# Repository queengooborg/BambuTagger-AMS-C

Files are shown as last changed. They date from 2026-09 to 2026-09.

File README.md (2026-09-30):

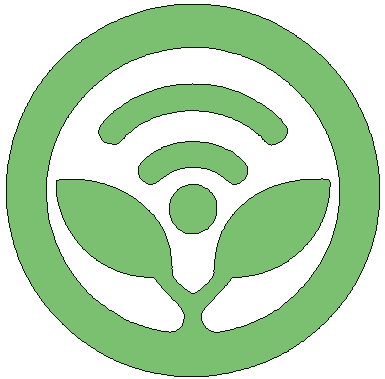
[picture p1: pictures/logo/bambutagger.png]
#  BambuTagger-AMS-C

Multi-spool NFC tag reader for Bambu Lab printers. Reads 4 Bambu Lab filament spool tags via RC522, displays live printer AMS tray data over MQTT, and sends RFID tag data to the printer/BMCU. Fully configurable via web interface with automatic AP fallback and OTA firmware updates.



<p align="center">
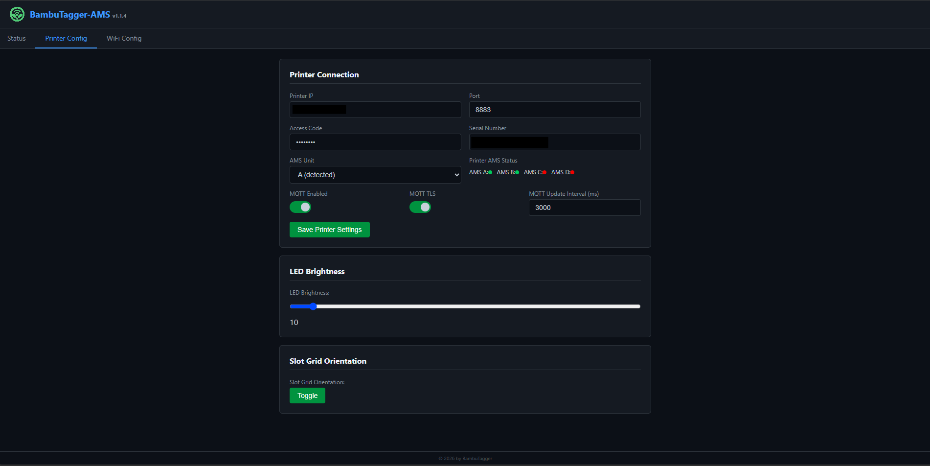
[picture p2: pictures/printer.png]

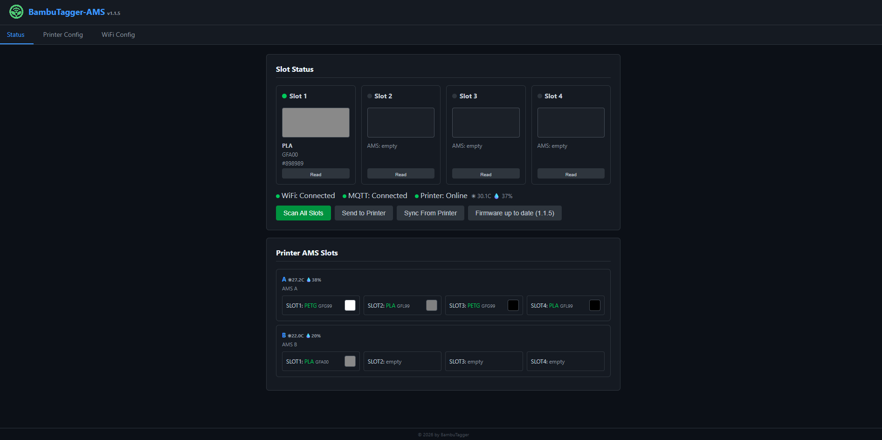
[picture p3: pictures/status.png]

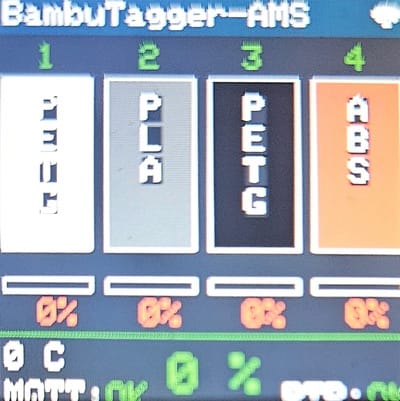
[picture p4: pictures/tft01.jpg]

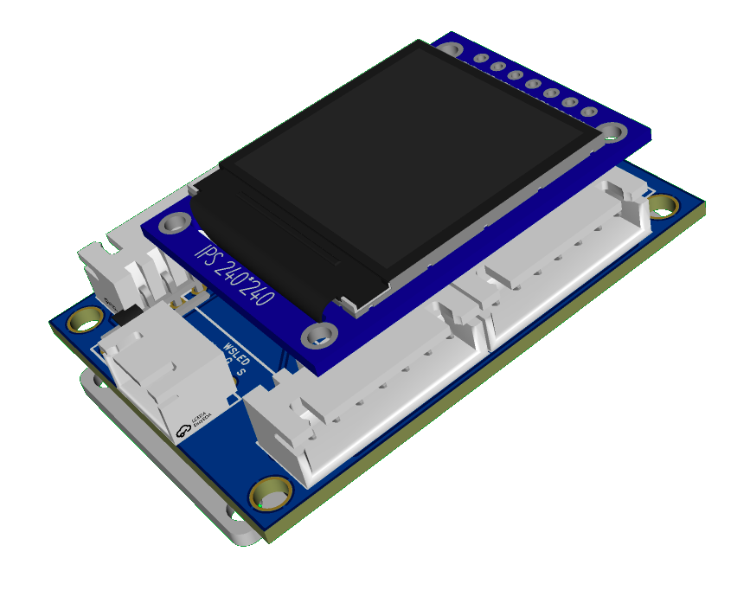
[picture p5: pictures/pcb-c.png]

</p>

Supported Tag Formats:

| Tag Type | Format |
| --- | --- |
| **Bambu Lab** | MIFARE Classic 1K |
| **SpoolEase** | NTAG, NDEF URI |
| **OpenSpool** | NTAG, NDEF JSON |
| **OpenTag3D** (v1 and v2) | NTAG, MIME binary |

---

## Features

| Category | Details |
| --- | --- |
| **RFID** | 4x RC522 on shared SPI bus; MIFARE Classic 1K (Bambu Lab) + NTAG (SpoolEase/OpenTag3D/OpenSpool) auto-detection |
| **Key derivation** | HKDF-SHA256 with Bambu Lab salt — no hardcoded keys |
| **Tag parsers** | OpenTag3D MIME binary, OpenSpool JSON, SpoolEase NDEF URI, nested NDEF recursion |
| **Live AMS sync**  | Reads tray data (material, color, type) from printer over MQTT |
| **BMCU support** | Sends `ams_filament_setting` with correct `tray_type`, `tray_color`, `nozzle_temp_min/max` |
| **TFT display** | 240×240 1.3" ST7789VW with boot splash, live AMS tray data, OTA progress, BME280 temp/humidity |
| **LEDs** | 4x WS2812 addressable LEDs with per-slot color from printer AMS tray data |
| **Web UI** | 3-tab SPA: Status (merged slots + color swatches), Printer Config, WiFi Config |
| **MQTT bridge** | Subscribes to printer status, publishes `ams_filament_setting` commands |
| **WiFi** | Auto-STA on boot; AP fallback `192.168.4.1` with captive portal |
| **OTA updates** | One-click firmware update from GitHub Releases with TFT progress bar |
| **CI/CD** | GitHub Actions: build on commit, release on version tags |

---

## Hardware

This build assumes you have a basic level of microprocessor and breadboard/soldering experience.

### Bill of Materials

There are two options for ESP32 boards: the ESP-WROOM-32 Dev board, or the ESP32-S3-DevKitC-1.

#### ESP-WROOM-32

This is the original board.

| Component | Required | Notes | Buy/Download/Get |
| --- | --- | --- | --- |
| **ESP32** Dev Module | **Yes**  | Base board | https://de.aliexpress.com/item/1005006589341221.html |
| Custom **PCB** | Optional | DIY PCB from JLPCB (use PCB v1.2 or newer) | https://oshwlab.com/bambutagger/project_hdkkdlsn |
| 3D-Printed **Case**  | Optional | | For [AMS](./3d-prints/ESP-WROOM-32/BambuTagger-AMS.3mf)<br /> For [AMS 2 Pro](./3d-prints/ESP-WROOM-32/BambuTagger-AMS2Pro.3mf) |

#### ESP32-S3-DevKitC-1

| Component | Required | Notes | Buy/Download/Get |
| --- | --- | --- | --- |
| **ESP32** Dev Module | **Yes**  | Base board | |
| Custom **PCB** | Optional | DIY PCB designed by @Digitalpunk | [Gerber Files](./PCB/ESP32-S3-DevKitC-1) |

#### Common Components

| Component | Required | Notes | Buy/Download/Get |
| --- | --- | --- | --- |
| **100µF Capacitor** | **Yes** | Regulates power for components | |
| **4x RC522** RFID/NFC Readers | **Yes** | SPI interface, shared bus | https://de.aliexpress.com/item/1005006233005745.html  |
| **240×240 1.3" TFT** | **Yes** | ST7789VW SPI Display | https://www.aliexpress.com/item/1005007094147766.html |
| **4x WS2812** Addressable LEDs | Optional | Daisy-chained, single data pin | https://de.aliexpress.com/item/32560280169.html |
| **BME280** 3.3V Sensor | Optional | Temperature/Humidity, I2C | https://de.aliexpress.com/item/1005006824236173.html  |
| **4x JST-XH 7-Pin** Connector+Cable | With Custom PCB | For PCB connections to RC522s  | |

### Wiring / Pin Assignments

If you are not using the custom PCB, you can manually wire all the components.

Connect the ESP32 to a 5V power input, either via the USB port or via the VCC/Vin pin.

The WS2812 LED must also be powered by 5V. If the ESP32 is powered via the USB port, the VCC/Vin pin becomes a 5V output, and can be used to power the LEDs. On some boards, you may need to short two pads (usually labeled VIN->VOUT) via soldering.

Connect the 100µF capacitor from the 3.3V to the ground. This capacitor helps regulate power and prevents back-powering the RC522 readers.

All other components will be powered by the 3.3V pin on the ESP32 board.

| Function | ESP-WROOM-32 | ESP32-S3-DevKitC-1 |
| --- | --- | --- |
| **RC522 SPI MOSI (Shared)** | 23 | 11 |
| **RC522 SPI MISO (Shared)** | 19 | 13 |
| **RC522 SPI SCK (Shared)**  | 18 | 12 |
| **RC522 #1 SS (SDA)** | 13 | 4 |
| **RC522 #1 RST** | 26 | 15 |
| **RC522 #2 SS (SDA)** | 12 | 5 |
| **RC522 #2 RST** | 25 | 16 |
| **RC522 #3 SS (SDA)** | 14 | 6 |
| **RC522 #3 RST** | 33 | 17 |
| **RC522 #4 SS (SDA)** | 27 | 7 |
| **RC522 #4 RST** | 32 | 18 |
| **TFT SDA (MOSI)** | 17 | 35 |
| **TFT SCL (SCK)** | 16 | 36 |
| **TFT DC** | 4 | 37 |
| **TFT RES** | 5 | 0 |
| **TFT BLK** | 2 | 45 |
| **WS2812 Data** | 15 | 14 |
| **BME280 SDA** | 21 | 48 |
| **BME280 SCL** | 22 | 47 |

---

## Firmware

### Flashing a Release

The easiest way to flash the board firmware is to use a web flashing utility like [ESPFlasher.app](https://espflasher.app/). Simply download the appropriate `firmware_merged.bin` from the [releases](https://github.com/queengooborg/BambuTagger-AMS-C/releases) page and upload it to the flashing utility.

- ESP-WROOM-32 / ESP32 Dev Module - `esp32dev-firmware_merged.bin`
- ESP32-S3-DevKitC-1 - `esp32-s3-devkitc-1-firmware_merged.bin`

Alternatively, if you have `esptool` set up locally, you may run the following command:

- ESP-WROOM-32 / ESP32 Dev Module - `esptool write-flash 0x0 esp32dev-firmware_merged.bin`
- ESP32-S3-DevKitC-1 - `esptool --chip esp32s3 write-flash 0x0 esp32-s3-devkitc-1-firmware_merged.bin`

### Building from Source

To build from source, you may either use Visual Studio Code or run commands in the terminal. The following sections will cover setup for running commands in the terminal.

#### Initial Setup

To setup the local development environment, you can either use Visual Studio Code, or run the `./setup.sh` command. The command will create a Python virtual environment, using the virtualenv manager if one is available, and install dependencies.

> [!NOTE]
> To reactivate the virtualenv at a later time (if you don't have a virtualenv manager), simply run:
>
> ```sh
> source .venv/bin/activate
> ```

#### Build and Upload

```sh
# ESP32-WROOM / ESP32 Dev Module
pio run -e esp32-ams-c
pio run -e esp32-ams-c -t upload

# ESP32-S3-DevKitC-1
pio run -e esp32-s3-devkitc-1
pio run -e esp32-s3-devkitc-1 -t upload
```

---

## How to Use

### Initial Setup

Once the firmware has been flashed for the first time, the ESP32 will initialize and create its own WiFi access point called "BambuTagger-AMS". Connect to the WiFi network to access the web-based configuration panel.

> [!NOTE]
> The configuration panel should automatically appear as a captive portal. If it does not, manually go to it by going to `http://192.168.4.1` in your browser.

Configure your WiFi network first by typing in the SSID name and password, then click "Save WiFi Settings". The ESP32 will reboot automatically. If the network configuration succeeded, you can now switch to your primary WiFi. If it did not, the WiFi access point will reinitialize, allowing you to reconnect.

Once WiFi configuration is completed, reconnect to your device by navigating to `[Device Name].local` (default: `BambuTagger-AMS.local`) or via the IP address displayed on the TFT screen.

Enter in your printer settings on the printer config page, including the IP, serial number and access code.

> [!IMPORTANT]
> Your printer MUST be in LAN Only Mode and Developer Mode. The printer will refuse all connections otherwise.

### Using with Printer

The project is designed with the intent of placing a reader at each AMS slot, similar to how the existing readers are placed. With each reader placed, tag scanning will happen automatically as filament is loaded normally.

--

## Technical Details

### WiFi & Connectivity

#### AP Mode

| Scenario | Behavior |
| --- | --- |
| No WiFi configured | Opens AP immediately |
| WiFi connection fails | Opens AP after 15 seconds |
| AP active, credentials exist | Retries STA connection every 30 seconds |
| STA connects while AP active | Closes AP, switches to normal mode |

**AP Details:**

- **SSID**: Device name (default: `BambuTagger-AMS`)
- **Security**: Open (no password)
- **IP**: `192.168.4.1`
- **Captive portal**: DNS redirects all domains to the config page

#### SSID Mode

When the ESP32 module is connected to an existing network, the IP address will display on the TFT screen. Alternatively, you may navigate to `[Device Name].local` (default: `BambuTagger-AMS.local`).

---

### Web Interface

Open a browser to the ESP32's IP (shown on TFT), `[Device Name].local`, or `http://192.168.4.1` (in AP mode).

| Tab | Description |
| --- | --- |
| **Status** | Merged slot status with AMS data + scanned tag data, color swatches, printer AMS cards, OTA button |
| **Printer Config** | Printer IP, Port (8883), Access Code, Serial Number, AMS Unit selector (A/B/C/D), MQTT settings |
| **WiFi Config** | SSID, Password, Device Name |

---

### TFT Display (240×240 1.3" ST7789VW)

The TFT display has two modes:

```
┌─────────────────────────────────┐
│ Device Name               WiFi  │  ← status bar (white bg)
├─────────────────────────────────┤
│    1       2                    │
│ ┌─────┐ ┌─────┐ ┌─────┐ ┌─────┐ │  ← color swatch + percentage
│ │  P  │ │     │ │     │ │     │ │
│ │  L  │ │     │ │     │ │     │ │
│ │  A  │ │     │ │     │ │     │ │
│ │     │ │     │ │     │ │     │ │
│ │     │ │     │ │     │ │     │ │
│ └─────┘ └─────┘ └─────┘ └─────┘ │
│                                 │
│  100%                           │
├─────────────────────────────────┤
│ 22C           45%               │  ← temperature, humidity
│ MQTT:OK                  PTR:OK │  ← status line
└─────────────────────────────────┘
```

```
┌─────────────────────────────────┐
│ Device Name               WiFi  │  ← status bar (white bg)
├─────────────────────────────────┤
│ 1: PLA     [■] #C0C0C0FF  100%  │  ← color swatch + percentage
│ 2: empty                        │
│ 3: empty                        │
│ 4: empty                        │
├─────────────────────────────────┤
│ 22C           45%               │  ← temperature, humidity
│ MQTT:OK                  PTR:OK │  ← status line
└─────────────────────────────────┘
```

OTA progress shown on TFT with header/footer preserved:  
"OTA Update" → "Downloading..." → "Flashing... 45%" → auto-reboot

---

### Printer Communication

#### Subscribe

- **Topic**: `device/<serial>/report`
- **Data**: `push_status` (periodic, ~3KB), `get_version` responses

#### Publish

- **Topic**: `device/<serial>/request`

**`ams_filament_setting`** structure:

```json
{
  "print": {
    "sequence_id": "0",
    "command": "ams_filament_setting",
    "ams_id": 0,
    "tray_id": 0,
    "tray_info_idx": "GFA00",
    "tray_color": "RRGGBBFF",
    "nozzle_temp_min": 190,
    "nozzle_temp_max": 230,
    "tray_type": "PLA"
  }
}
```

- `tray_type` derived from filament index prefix (GFA→PLA, GFG→PETG, etc.)
- `tray_color` forced to RRGGBBFF format
- `nozzle_temp_min/max` from tag block 6

---

### Tag Format & Reading

The following tag types are supported:

| Tag Type | Format | Example |
| --- | --- | --- |
| **Bambu Lab** | MIFARE Classic 1K | `Bambu - PLA · C12E1FFF · 1000g/1000g` |
| **SpoolEase** | NTAG, NDEF URI | `SpoolEase - PLA · 000000FF · 1000g/1036g` |
| **OpenSpool** | NTAG, NDEF JSON | `OpenSpool - ASA-AF · F078B4FF · 1000g/1000g` |
| **OpenTag3D** (v1 and v2) | NTAG, MIME binary | `OpenTag3D v2.003 - ASA-AF · F078B4FF · 1000g/1000g` |

#### Bambu Lab (MIFARE Classic 1K)

| Block | Content |
| ----- | --- |
| 0 | UID (4 bytes) |
| 1 | Variant ID + Material index (e.g. "GFA00") |
| 2 | Filament type short name |
| 4 | Detailed type string (e.g. "PLA Basic") |
| 5 | RGBA color (bytes 0-3) + spool weight LE (bytes 4-5) |
| 6 | Nozzle temps (bytes 8-11 LE) |

#### SpoolEase (NTAG, NDEF URI)

URL format: `https://tag.spoolease.io/S1/?TG=...&M=PLA&CC=000000FF&SC=GFL99&WL=1000&WE=179&WF=1215&NN=190&NX=240`

| Param | Field | Description |
| ----- | --- | --- |
| `M=`  | display type | e.g. "PLA", "PETG" |
| `SC=` | `materialType` | Bambu index for MQTT (e.g. "GFL99") |
| `CC=` | `colorHex` | RGBA hex (e.g. "000000FF") |
| `B=`  | `manufacturer` | Brand name (e.g. "Jayo") |
| `WL=` | `remainingGrams` | Remaining filament weight |
| `WE=` | empty spool | Empty spool weight |
| `WF=` | full spool | `totalGrams = WF - WE` |
| `NN=` | `nozzleTempMin`  | Min nozzle temp °C |
| `NX=` | `nozzleTempMax`  | Max nozzle temp °C |

#### OpenTag3D (NTAG, MIME binary)

The OpenTag3D spec can be read on [their website](https://opentag3d.info/spec).

### Authentication & Reading

- **Tag auto-detect**: SAK-based type detection (MIFARE 1K vs NTAG)
- **HKDF-SHA256** derives 16 per-sector Key A/B from 4-byte UID
- Bambu KDF salt/info vectors from reverse-engineered firmware
- Falls back to default key `0xFF...FF` for blank sectors
- Failed auth re-wakes tag via antenna power-cycle
- Dead readers auto-skipped (version register 0x92/0x91/0xB2 check)
- SPI: 1 MHz via `MFRC522_SPI`
- NTAG: page-level reads (page+=4, 4 pages per MIFARE_Read)

### Filament Type Mapping

| Prefix | Type |
| --- | ---- |
| GFA-GFE, GFL | PLA  |
| GFG | PETG |
| GFH, GFI | ABS  |
| GFJ | ASA  |
| GFK | TPU  |

---

### OTA Updates

- **Button**: "Update Firmware" on Status page (shows "Update to vX.Y.Z" or "up to date")
- **Overlay**: full-screen progress overlay with spinner, status text, progress bar
- **Endpoint**: `POST /api/ota` triggers update, `GET /api/ota-check` checks for newer version
- Downloads latest `.ino.bin` from GitHub Releases, flashes via `Update.h`
- 3 retry attempts with 5s stall detection, fresh HTTP client per attempt
- TFT shows "Checking version..." → "Downloading..." → "Flashing..." with percentage
- Device auto-reboots after successful flash, web UI auto-reloads

---

### Configuration Defaults

| Setting | Default |
| --- | --- |
| WiFi SSID | (empty) |
| WiFi Password | (empty) |
| Device Name | BambuTagger-AMS |
| Printer IP | 192.168.1.100 |
| Printer Port | 8883 |
| Access Code | (empty) |
| Printer Serial | (empty) |
| AMS Unit | A (0) |
| MQTT Enabled | Yes |
| MQTT TLS | No |
| MQTT Update Interval | 3000 ms |
| RFID Poll Interval | 100 ms |
| Firmware Version | 1.0.8 |

---

## Credits & References

- [RFID-Tag-Guide](https://github.com/Bambu-Research-Group/RFID-Tag-Guide)
- Display library: [Adafruit ST7735/ST7789](https://github.com/adafruit/Adafruit-ST7735-Library)
- RFID library: [MFRC522-spi-i2c-uart-async](https://github.com/miguelbalboa/rfid)
- OpenTag3D spec: [opentag3d.info](https://opentag3d.info)

---

## License

This project is licened under AGPLv3.
This project is provided as-is for personal and educational use.  
Bambu Lab trademarks and spool tag data formats are the property of Bambu Lab.

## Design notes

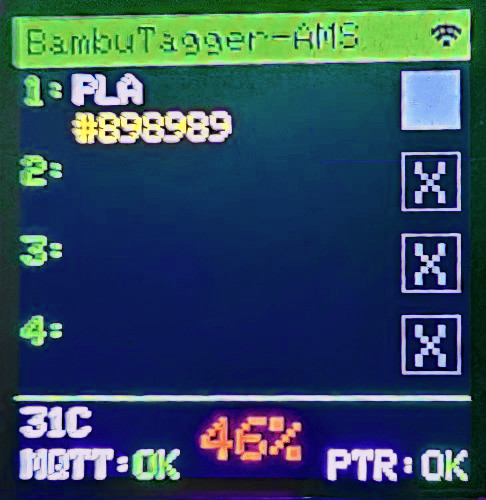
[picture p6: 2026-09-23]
pictures/tft02.jpg

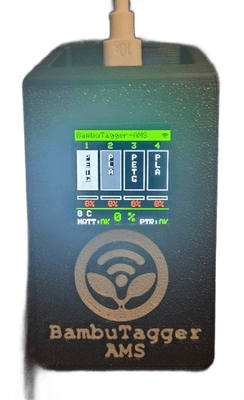
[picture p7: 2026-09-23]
pictures/BT-AMS-case.png

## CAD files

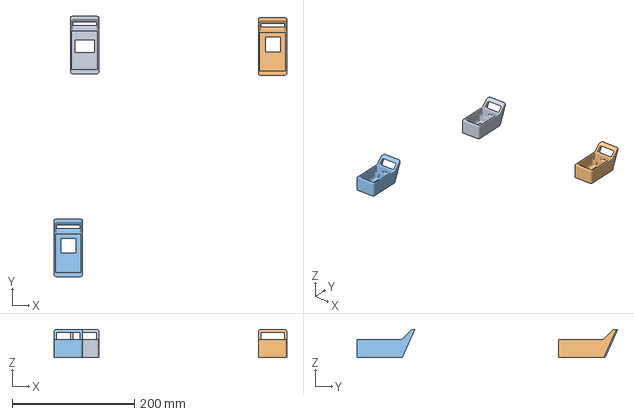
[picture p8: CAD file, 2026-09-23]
3d-prints/ESP-WROOM-32/BambuTagger-AMS.3mf
381.9 x 427.1 x 46.1 mm
BambuTagger-AMS
BambuTagger-AMS-C x 2

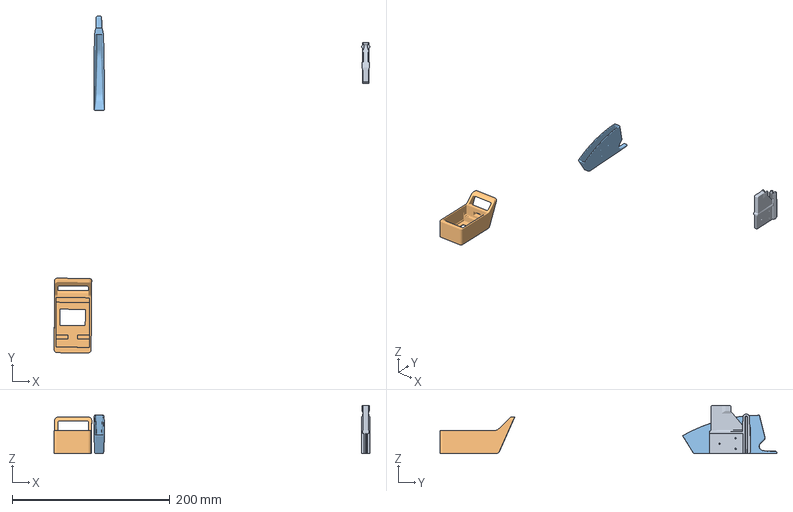
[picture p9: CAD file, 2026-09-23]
3d-prints/ESP-WROOM-32/BambuTagger-AMS2Pro.3mf
400.6 x 427.3 x 61.2 mm
BambuTagger-AMS (2).stl
BambuTagger-AMS.stl
BambuTagger-AMS (1).stl

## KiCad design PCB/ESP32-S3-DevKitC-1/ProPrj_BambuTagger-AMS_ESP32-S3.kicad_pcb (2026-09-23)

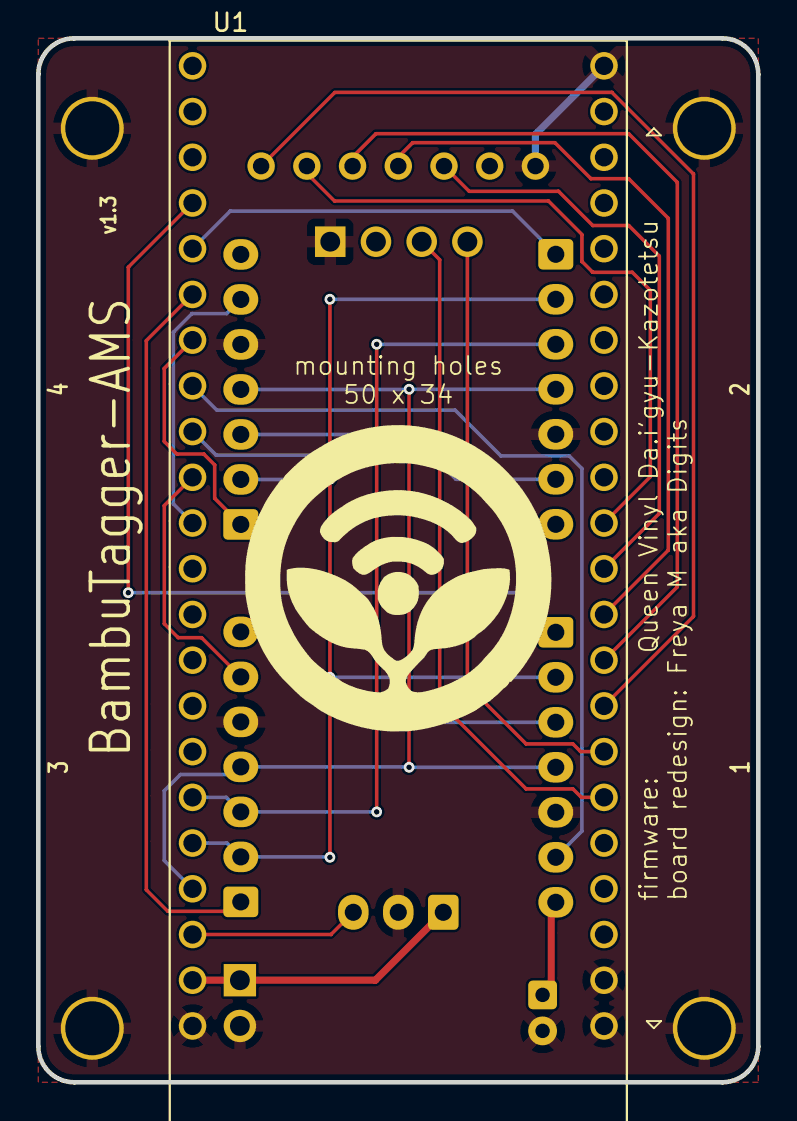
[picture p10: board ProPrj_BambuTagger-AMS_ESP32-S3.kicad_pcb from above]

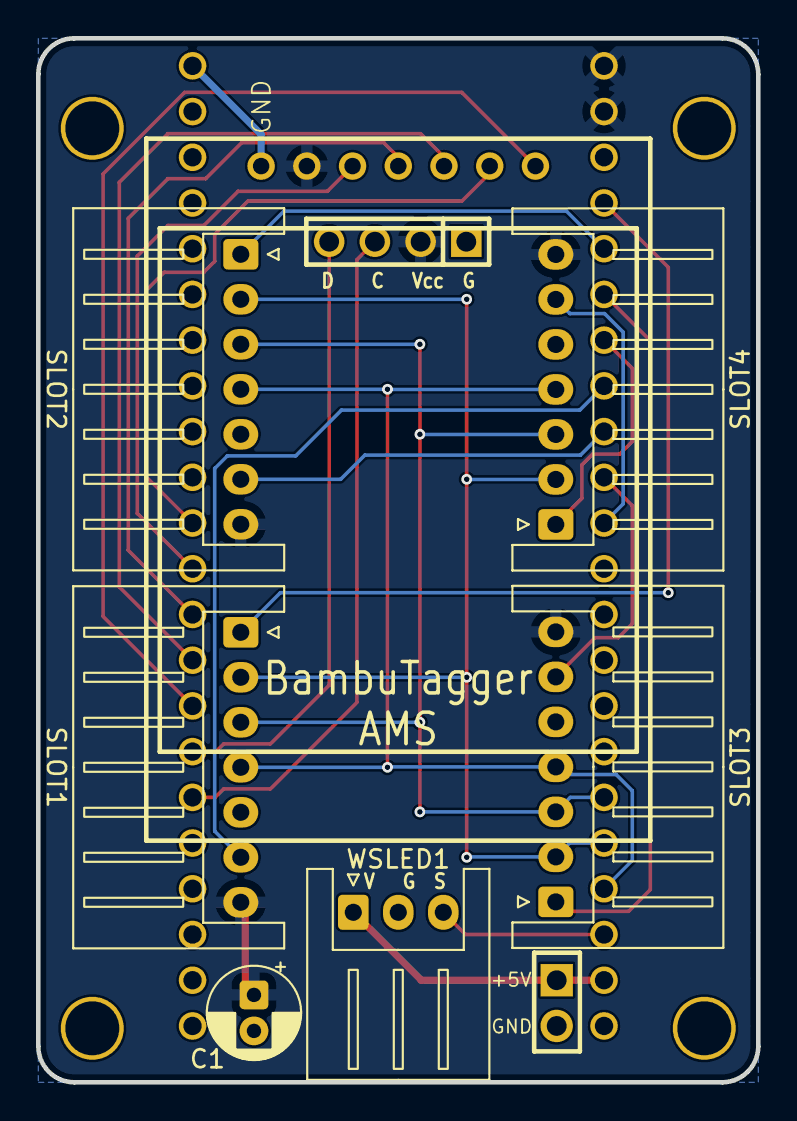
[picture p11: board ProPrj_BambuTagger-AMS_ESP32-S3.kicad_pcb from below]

Board: 2 copper layers, 40.0 x 58.0 mm, 10 parts (9 on the bottom side), 22 nets.

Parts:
5V: HDR-TH_2P-P2.54-H-M-W10.4
C1: 100uF; CP_Radial_D5.0mm_P2.00mm
SENSOR: HDR-TH_4P-P2.54-V-M
SLOT1, SLOT2, SLOT3, SLOT4: ZX-XH2.54-7PWZ; JST_XH_S7B-XH-A_1x07_P2.50mm_Horizontal
TFT: 240X240 1.3 TFT SPI DISPLAY
U1: ESP32-S3-DEVKITC-1U-N8R8; MODULE_ESP32-S3-DEVKITC-1U-N8R8
WSLED1: ZX-XH2.54-3PWZ; JST_XH_S3B-XH-A_1x03_P2.50mm_Horizontal

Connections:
3_3V: C1.1, SENSOR.2, SLOT1.7, SLOT2.7, SLOT3.7, SLOT4.7, TFT.6, U1.J1_1 (3V3), U1.J1_2 (3V3)
BLK: TFT.1, U1.J3_15 (GPIO45)
CS1: SLOT1.1, U1.J1_4 (GPIO4)
CS2: SLOT2.1, U1.J1_5 (GPIO5)
CS3: SLOT3.1, U1.J1_6 (GPIO6)
CS4: SLOT4.1, U1.J1_7 (GPIO7)
DC: TFT.2, U1.J3_11 (GPIO37)
GND: 5V.2, C1.2, SENSOR.1, SLOT1.5, SLOT2.5, SLOT3.5, SLOT4.5, TFT.7, U1.J1_22 (GND), U1.J3_1 (GND), U1.J3_21 (GND), U1.J3_22 (GND), WSLED1.2
MISO: SLOT1.4, SLOT2.4, SLOT3.4, SLOT4.4, U1.J1_19 (GPIO13)
MOSI: SLOT1.3, SLOT2.3, SLOT3.3, SLOT4.3, U1.J1_17 (GPIO11)
RES: TFT.3, U1.J3_14 (GPIO0)
RST1: SLOT1.6, U1.J1_8 (GPIO15)
RST2: SLOT2.6, U1.J1_9 (GPIO16)
RST3: SLOT3.6, U1.J1_10 (GPIO17)
RST4: SLOT4.6, U1.J1_11 (GPIO18)
SCK: SLOT1.2, SLOT2.2, SLOT3.2, SLOT4.2, U1.J1_18 (GPIO12)
SCL: SENSOR.3, U1.J3_17 (GPIO47)
SCLTFT: TFT.5, U1.J3_12 (GPIO36)
SDA: SENSOR.4, U1.J3_16 (GPIO48)
SDATFT: TFT.4, U1.J3_13 (GPIO35)
VCC: 5V.1, U1.J1_21 (5V0), WSLED1.1
WSLED: U1.J1_20 (GPIO14), WSLED1.3

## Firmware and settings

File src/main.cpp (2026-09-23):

/*
 * BambuTagger AMS - Multi-Spool NFC Tag Reader for Bambu Lab
 *
 * Arduino IDE: ESP32 Dev Module (Tools > Board > ESP32 > ESP32 Dev Module)
 *
 * Required libraries (install via Tools > Manage Libraries):
 *   - MFRC522-spi-i2c-uart-async
 *   - Adafruit NeoPixel by Adafruit    (v1.12.3+)
 *   - Adafruit GFX Library by Adafruit (v1.11.11+)
 *   - Adafruit ST7735 and ST7789 Library by Adafruit (v1.10.0+)
 *   - PubSubClient   by Nick O'Leary   (v2.8+)
 *   - ArduinoJson    by Benoit Blanchon (v6.21.5+)
 *
 * Wiring: see config.h for pin assignments
 */

#include <ESPmDNS.h>
#include <WiFi.h>
#include <DNSServer.h>
#include <HTTPClient.h>
#include <Update.h>
#include <Adafruit_BME280.h>
#include <HTTPUpdate.h>

#include <esp_http_client.h>
#include <esp_ota_ops.h>

#include "config.h"
#include "rfid_manager.h"
#include "led_manager.h"
#include "display_manager.h"
#include "web_server.h"
#include "bambu_printer.h"

SystemConfig cfg;
RfidManager rfidManager;
LedManager ledManager;
DisplayManager displayManager;
WebInterface webInterface;
BambuPrinter bambuPrinter;
DNSServer dnsServer;
Adafruit_BME280 bme;
float bmeTemp = 0;
float bmeHumidity = 0;
bool bmeOk = false;

bool wifiConnected = false;
bool apMode = false;
String localIP = "";
const byte DNS_PORT = 53;

void handleReboot();
void performOTAUpdate();
void connectWiFi();
void startCaptivePortal();
void updateLedStatus();

SET_LOOP_TASK_STACK_SIZE(16 * 1024);

void setup() {
  Serial.begin(115200);
  delay(1500);
  Serial.println();
  Serial.print(F("=== BambuTagger AMS v"));
  Serial.print(FIRMWARE_VERSION);
  Serial.println(F(" ==="));
  Serial.println(F("Multi-Spool NFC Tag Reader for Bambu Lab"));

  loadConfig(cfg);

  displayManager.begin(cfg.deviceName);
  Serial.println(F("TFT initialized"));
  displayManager.showBootScreen();
  displayManager.setLayout(cfg.layoutVertical);
  delay(2000);

  Wire.begin(I2C_SDA, I2C_SCL);
  bmeOk = bme.begin(0x76);
  if (!bmeOk)
    bmeOk = bme.begin(0x77);
  if (bmeOk) {
    Serial.println(F("BME280 sensor found"));
  } else {
    Serial.println(F("BME280 not found"));
  }

  Serial.print(F("Device: "));
  Serial.println(cfg.deviceName);

  ledManager.begin();
  Preferences prefs;
  prefs.begin("led", false);
  uint8_t savedBrightness = prefs.getUChar("brightness", LED_BRIGHTNESS);
  prefs.end();

  ledManager.setBrightness(savedBrightness);

  ledManager.setAllLeds(LED_IDLE);
  ledManager.update();

  rfidManager.begin();
  Serial.println(F("RFID readers initialized"));

  connectWiFi();

  if (wifiConnected) {
    bambuPrinter.begin(cfg);
  }

  webInterface.begin(cfg, &rfidManager, &bambuPrinter, handleReboot, performOTAUpdate);
  webInterface.updateStatus(wifiConnected, localIP.c_str(), false, false);

  ledManager.setAllLeds(wifiConnected ? LED_WIFI_CONNECTED : LED_WIFI_DISCONNECTED);
  ledManager.update();

  Serial.println(F("Setup complete"));
}

void loop() {
  rfidManager.loop();
  webInterface.handleClient();
  yield();
  if (apMode) {
    dnsServer.processNextRequest();
  }
  if (wifiConnected) {
    static unsigned long lastMqttLoop = 0;
    if (millis() - lastMqttLoop > 200) {
      lastMqttLoop = millis();
      bambuPrinter.update();
    }
  }

  static unsigned long lastReconnectCheck = 0;
  static unsigned long lastLedUpdate = 0;
  static unsigned long lastDisplayUpdate = 0;
  static unsigned long lastMqttUpdate = 0;
  static unsigned long lastWifiStateCheck = 0;
  unsigned long now = millis();

  if (now - lastWifiStateCheck > 1000) {
    lastWifiStateCheck = now;

    if (WiFi.status() == WL_CONNECTED) {
      if (!wifiConnected || apMode) {
        wifiConnected = true;
        apMode = false;
        localIP = WiFi.localIP().toString();
        dnsServer.stop();
        Serial.print(F("WiFi connected! IP: "));
        Serial.println(localIP);
        displayManager.showOtaProgress("WiFi Connected", localIP.c_str());
        bambuPrinter.begin(cfg);
        if (MDNS.begin(cfg.deviceName)) {
          Serial.println(F("mDNS responder started"));
        }
      }
    } else if (!apMode && strlen(cfg.wifiSSID) > 0 && now - lastReconnectCheck > 15000) {
      lastReconnectCheck = now;
      Serial.println(F("WiFi not connected yet — retrying in background..."));
      WiFi.disconnect(false);
      WiFi.begin(cfg.wifiSSID, cfg.wifiPassword);
    }
  }

  if (apMode && strlen(cfg.wifiSSID) > 0 && now - lastReconnectCheck > 30000) {
    lastReconnectCheck = now;
    Serial.println(F("AP Mode: retrying STA connection..."));
    WiFi.begin(cfg.wifiSSID, cfg.wifiPassword);
  }

  static unsigned long lastBmeRead = 0;
  if (bmeOk && now - lastBmeRead > 5000) {
    lastBmeRead = now;
    bmeTemp = bme.readTemperature();
    bmeHumidity = bme.readHumidity();
  }

  static unsigned long lastBmeSend = 0;
  if (bmeOk && now - lastBmeSend > 60000) {
    lastBmeSend = now;
    bambuPrinter.sendBmeData(bmeTemp, bmeHumidity);
  }

  if (now - lastLedUpdate > 200) {
    lastLedUpdate = now;
    updateLedStatus();
    ledManager.update();
  }

  if (now - lastDisplayUpdate > 2000) {
    lastDisplayUpdate = now;
    SpoolInfo displaySlots[NUM_SLOTS];
    for (uint8_t i = 0; i < NUM_SLOTS; i++) {
      rfidManager.getSpoolInfo(i, displaySlots[i]);
    }
    bool mqttOk = bambuPrinter.isConnected();
    webInterface.updateStatus(wifiConnected, localIP.c_str(), mqttOk,
                              (bambuPrinter.getState() == PRINTER_CONNECTED));
    displayManager.update(displaySlots, wifiConnected, mqttOk, bmeOk, &bambuPrinter, cfg.amsUnit,
                          bmeTemp, bmeHumidity);
  }

  if (now - lastMqttUpdate > (cfg.mqttUpdateIntervalMs > 0 ? cfg.mqttUpdateIntervalMs : 5000)) {
    lastMqttUpdate = now;
    if (wifiConnected) {
      bool mqttOk = bambuPrinter.isConnected();
      webInterface.updateStatus(wifiConnected, localIP.c_str(), mqttOk,
                                (bambuPrinter.getState() == PRINTER_CONNECTED));

      if (cfg.mqttEnabled && mqttOk) {
        for (uint8_t i = 0; i < NUM_SLOTS; i++) {
          SpoolInfo info;
          if (rfidManager.getSpoolInfo(i, info) && info.present && info.tagReadSuccess) {
            bambuPrinter.sendSpoolData(i, info);
          }
        }
      }
    }
  }
}

void connectWiFi() {
  if (strlen(cfg.wifiSSID) == 0) {
    Serial.println(F("No WiFi credentials configured — starting AP"));
    wifiConnected = false;
    startCaptivePortal();
    return;
  }

  Serial.print(F("Connecting to WiFi: "));
  Serial.println(cfg.wifiSSID);

  WiFi.setHostname(cfg.deviceName);
  WiFi.mode(WIFI_STA);
  WiFi.begin(cfg.wifiSSID, cfg.wifiPassword);

  ledManager.setAllLeds(LED_WIFI_DISCONNECTED);
  ledManager.update();

  // Do not block the main loop here. The ESP32 web server must keep responding
  // while the WiFi stack connects in the background.
  wifiConnected = false;
  apMode = false;
}

void startCaptivePortal() {
  apMode = true;
  WiFi.mode(WIFI_AP);
  WiFi.softAP(cfg.deviceName, NULL);
  delay(100);

  IPAddress apIP(192, 168, 4, 1);
  WiFi.softAPConfig(apIP, apIP, IPAddress(255, 255, 255, 0));
  localIP = "192.168.4.1";

  dnsServer.start(DNS_PORT, "*", apIP);

  Serial.print(F("AP started: "));
  Serial.print(cfg.deviceName);
  Serial.println(F(" (open)"));
  Serial.println(F("Connect and visit http://192.168.4.1"));

  char apMsg1[32];
  char apMsg2[32];
  char apMsg3[32];
  snprintf(apMsg1, sizeof(apMsg1), "WiFi: %s", cfg.deviceName);
  snprintf(apMsg2, sizeof(apMsg2), "IP: 192.168.4.1");
  snprintf(apMsg3, sizeof(apMsg3), "Configure WiFi");
  displayManager.showOtaProgress(apMsg1, apMsg2, apMsg3);
}

static uint8_t hexToByte(const char* hex) {
  uint8_t val = 0;
  for (uint8_t i = 0; i < 2; i++) {
    char c = hex[i];
    val <<= 4;
    if (c >= '0' && c <= '9')
      val |= (c - '0');
    else if (c >= 'A' && c <= 'F')
      val |= (c - 'A' + 10);
    else if (c >= 'a' && c <= 'f')
      val |= (c - 'a' + 10);
  }
  return val;
}

void updateLedStatus() {
  uint8_t amsUnit = cfg.amsUnit;
  for (uint8_t i = 0; i < NUM_SLOTS; i++) {
    if (!wifiConnected && !apMode) {
      ledManager.setSlotLed(i, LED_WIFI_DISCONNECTED);
    } else if (apMode) {
      ledManager.setSlotLed(i, LED_IDLE);
    } else if (bambuPrinter.isAmsDetected(amsUnit)) {
      const char* col = bambuPrinter.getAmsTrayColor(amsUnit, i);
      if (col && col[0]) {
        uint8_t r = hexToByte(col);
        uint8_t g = hexToByte(col + 2);
        uint8_t b = hexToByte(col + 4);
        ledManager.setSlotColor(i, r, g, b);
      } else {
        ledManager.setSlotLed(i, LED_IDLE);
      }
    } else {
      ledManager.setSlotLed(i, LED_IDLE);
    }
  }
}

void handleReboot() {
  Serial.println(F("Reboot requested via web..."));
  delay(500);
  ESP.restart();
}

void performOTAUpdate() {
  static bool otaRunning = false;
  if (otaRunning)
    return;
  otaRunning = true;
  displayManager.showOtaProgress("OTA Update", "Checking version...");

  String dlUrl;
  int binSize = 0;
  String tag;

  {
    // Get latest tag via redirect — no API, no rate limits, no JSON
    WiFiClientSecure client;  // ← add this
    HTTPClient http;          // ← add this
    client.setInsecure();
    client.setTimeout(10000);
    http.setFollowRedirects(HTTPC_DISABLE_FOLLOW_REDIRECTS);
    http.begin(client, String("https://github.com/") + OTA_REPO + "/releases/latest");
    http.addHeader("User-Agent", String("BambuTagger-AMS/") + FIRMWARE_VERSION);
    const char* hdrs[] = {"Location"};
    http.collectHeaders(hdrs, 1);

    int code = http.GET();
    String latest = "";
    if ((code == 301 || code == 302) && http.hasHeader("Location")) {
      String loc = http.header("Location");
      int tagIdx = loc.lastIndexOf("/tag/");
      if (tagIdx >= 0)
        latest = loc.substring(tagIdx + 5);
    }
    http.end();

    if (latest.isEmpty()) {
      displayManager.showOtaProgress("OTA Update", "", "No release found");
      otaRunning = false;
      delay(3000);
      return;
    }

    // Version check
    tag = latest;
    const char* r = latest.c_str();
    if (r[0] == 'v' || r[0] == 'V')
      r++;
    const char* l = FIRMWARE_VERSION;
    if (l[0] == 'v' || l[0] == 'V')
      l++;
    int rMaj = 0, rMin = 0, rPat = 0, lMaj = 0, lMin = 0, lPat = 0;
    sscanf(r, "%d.%d.%d", &rMaj, &rMin, &rPat);
    sscanf(l, "%d.%d.%d", &lMaj, &lMin, &lPat);
    if (rMaj * 10000 + rMin * 100 + rPat <= lMaj * 10000 + lMin * 100 + lPat) {
      displayManager.showOtaProgress("OTA Update", "", "Already up to date");
      otaRunning = false;
      delay(3000);
      return;
    }

    // Construct download URL directly — no asset JSON needed
    dlUrl =
        String("https://github.com/") + OTA_REPO + "/releases/download/" + latest + "/firmware.bin";
    Serial.printf("[OTA] tag: %s\n", latest.c_str());
    Serial.printf("[OTA] dlUrl: %s\n", dlUrl.c_str());
  }  // ← client, http destroyed here — heap reclaimed

  if (!dlUrl.length()) {
    displayManager.showOtaProgress("OTA Update", "", "No .bin found");
    otaRunning = false;
    delay(3000);
    return;
  }

  displayManager.showOtaProgress("OTA Update", "Downloading...", tag.c_str());

  String finalUrl = dlUrl;
  {
    WiFiClientSecure rc;
    rc.setInsecure();
    rc.setTimeout(10000);
    HTTPClient rh;
    const char* hdrs[] = {"Location"};
    rh.collectHeaders(hdrs, 1);
    rh.begin(rc, dlUrl);
    rh.addHeader("User-Agent", String("BambuTagger-AMS/") + FIRMWARE_VERSION);
    rh.setFollowRedirects(HTTPC_DISABLE_FOLLOW_REDIRECTS);
    int code = rh.GET();
    Serial.printf("[OTA] redirect code: %d\n", code);
    if ((code == 301 || code == 302) && rh.hasHeader("Location")) {
      finalUrl = rh.header("Location");
      Serial.printf("[OTA] CDN URL: %s\n", finalUrl.c_str());
    }
    rh.end();
  }

  // Raw WiFiClientSecure — same as redirect blocks, bypasses IDF TLS enforcement
  String dlHost, dlPath;
  {
    String u = finalUrl;
    if (u.startsWith("https://"))
      u = u.substring(8);
    int si = u.indexOf('/');
    dlHost = (si >= 0) ? u.substring(0, si) : u;
    dlPath = (si >= 0) ? u.substring(si) : "/";
  }

  WiFiClientSecure dlClient;
  dlClient.setInsecure();
  dlClient.setTimeout(30000);

  displayManager.showOtaProgress("OTA Update", tag.c_str(), "Connecting...");
  if (!dlClient.connect(dlHost.c_str(), 443)) {
    Serial.println("[OTA] CDN connect failed");
    displayManager.showOtaProgress("OTA Update", "", "Connect failed");
    otaRunning = false;
    delay(3000);
    return;
  }

  // Send raw HTTP/1.1 GET
  dlClient.print(String("GET ") + dlPath + " HTTP/1.1\r\n");
  dlClient.print(String("Host: ") + dlHost + "\r\n");
  dlClient.print("User-Agent: BambuTagger-AMS/" FIRMWARE_VERSION "\r\n");
  dlClient.print("Connection: close\r\n\r\n");

  // Parse response headers
  int httpStatus = 0, contentLen = -1;
  {
    String line = dlClient.readStringUntil('\n');
    line.trim();
    if (line.length() > 9)
      httpStatus = line.substring(9, 12).toInt();
    Serial.printf("[OTA] HTTP status: %d\n", httpStatus);
    while (true) {
      line = dlClient.readStringUntil('\n');
      line.trim();
      if (line.isEmpty())
        break;
      String lower = line;
      lower.toLowerCase();
      if (lower.startsWith("content-length:")) {
        String val = line.substring(15);
        val.trim();
        contentLen = val.toInt();
      }
    }
    Serial.printf("[OTA] Content-Length: %d\n", contentLen);
  }

  if (httpStatus != 200 || contentLen <= 0) {
    dlClient.stop();
    displayManager.showOtaProgress("OTA Update", "", "Bad response");
    otaRunning = false;
    delay(3000);
    return;
  }

  const esp_partition_t* part = esp_ota_get_next_update_partition(NULL);
  esp_ota_handle_t otaHandle = 0;
  if (esp_ota_begin(part, contentLen, &otaHandle) != ESP_OK) {
    dlClient.stop();
    displayManager.showOtaProgress("OTA Update", "", "OTA begin failed");
    otaRunning = false;
    delay(3000);
    return;
  }

  uint8_t buf[2048];
  int written = 0, lastPct = -1;
  unsigned long lastData = millis();

  while (written < contentLen) {
    int avail = dlClient.available();
    if (avail > 0) {
      lastData = millis();
      int rd = dlClient.read(buf, min(avail, (int)sizeof(buf)));
      if (rd > 0) {
        esp_ota_write(otaHandle, buf, rd);
        written += rd;
        int pct = (written * 100) / contentLen;
        if (pct != lastPct) {
          Serial.printf("[OTA] progress: %d / %d\n", written, contentLen);
          displayManager.showOtaProgress("OTA Update", tag.c_str(), "Downloading...", pct);
          lastPct = pct;
        }
      }
    } else if (!dlClient.connected()) {
      Serial.printf("[OTA] connection closed at %d/%d\n", written, contentLen);
      break;
    } else {
      if (millis() - lastData > 30000) {
        Serial.printf("[OTA] stalled at %d/%d\n", written, contentLen);
        break;
      }
      delay(1);  // yield proper RTOS tick to Core-0 WiFi stack
    }
  }

  dlClient.stop();
  Serial.printf("[OTA] written: %d / %d\n", written, contentLen);

  if (written == contentLen) {
    esp_err_t err = esp_ota_end(otaHandle);
    if (err == ESP_OK)
      err = esp_ota_set_boot_partition(part);
    if (err == ESP_OK) {
      displayManager.showOtaProgress("OTA Update", "", "Update OK", 100);
      otaRunning = false;
      delay(2000);
      ESP.restart();
    } else {
      Serial.printf("[OTA] finalize error: 0x%x\n", err);
    }
  }

  displayManager.showOtaProgress("OTA Update", "", "OTA failed");
  otaRunning = false;
  delay(3000);
}

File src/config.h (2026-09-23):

#pragma once

#include <Arduino.h>
#include <Preferences.h>

#define FIRMWARE_VERSION "1.3.0-queengooborg"
#define OTA_REPO \
  "queengooborg/BambuTagger-AMS-C"  // "VID-PRO/BambuTagger-AMS-C" -- XXX restore once forked
                                    // changes are merged upstream

#define NUM_SLOTS 4

// --- Pin Assignments ---
// Pin assignments differ because the S3 DevKitC and classic ESP32 expose
// different GPIOs on their headers.
#ifdef BAMBU_TAGGER_ESP32_S3
// RC522 SPI pins
#define SPI_MOSI 11
#define SPI_MISO 13
#define SPI_SCK 12
const uint8_t SS_PINS[NUM_SLOTS] = {4, 5, 6, 7};
const uint8_t RST_PINS[NUM_SLOTS] = {15, 16, 17, 18};

// WS2812 LED daisy chain (single data pin, 4 LEDs in series)
#define LED_DATA_PIN 14

// SPI TFT (240x240 1.3" ST7789VW)
#define TFT_BLK 45
#define TFT_DC 37
#define TFT_RES 0
#define TFT_CS -1
#define TFT_SCL 36
#define TFT_SDA 35

// BME280 I2C pins
#define I2C_SDA 48
#define I2C_SCL 47
#else
// RC522 SPI pins
#define SPI_MOSI 23
#define SPI_MISO 19
#define SPI_SCK 18
const uint8_t SS_PINS[NUM_SLOTS] = {13, 12, 14, 27};
const uint8_t RST_PINS[NUM_SLOTS] = {26, 25, 33, 32};

// WS2812 LED daisy chain (single data pin, 4 LEDs in series)
#define LED_DATA_PIN 15

// SPI TFT (240x240 1.3" ST7789VW)
#define TFT_BLK 2
#define TFT_DC 4
#define TFT_RES 5
#define TFT_CS -1
#define TFT_SCL 16
#define TFT_SDA 17

// BME280 I2C pins
#define I2C_SDA 21
#define I2C_SCL 22
#endif

#define LED_COUNT 4
#define LED_BRIGHTNESS 32

// --- RFID Settings ---
#define RFID_POLL_INTERVAL_MS 250
#define RFID_DEBOUNCE_MS 750
#define NTAG_PAGE_SIZE 4
#define NTAG_USER_START_PAGE 4
#define NTAG_MAX_PAGES 231

// --- Spool Info Structure ---
struct SpoolInfo {
  bool present;
  char uid[16];
  char materialType[32];
  char detailedType[256];
  char color[16];
  char colorHex[9];
  uint16_t remainingGrams;
  uint16_t totalGrams;
  uint16_t nozzleTempMin;
  uint16_t nozzleTempMax;
  char batchNumber[32];
  char manufacturer[32];
  uint32_t lastSeen;
  bool tagReadSuccess;
};

// --- System Configuration ---
struct SystemConfig {
  char wifiSSID[32];
  char wifiPassword[64];
  char printerIP[16];
  uint16_t printerPort;
  char printerAccessCode[48];
  char printerSerial[32];
  char deviceName[32];
  uint8_t amsUnit;  // 0=A, 1=B, 2=C, 3=D
  bool mqttEnabled;
  bool mqttUseTLS;
  uint32_t mqttUpdateIntervalMs;
  char mqttTopicPrefix[64];
  bool layoutVertical;
};

// --- Default Configuration ---
inline SystemConfig getDefaultConfig() {
  SystemConfig cfg;
  strcpy(cfg.wifiSSID, "");
  strcpy(cfg.wifiPassword, "");
  strcpy(cfg.printerIP, "192.168.1.100");
  cfg.printerPort = 8883;
  strcpy(cfg.printerAccessCode, "");
  strcpy(cfg.printerSerial, "");
  strcpy(cfg.deviceName, "BambuTagger-AMS");
  cfg.amsUnit = 0;
  cfg.mqttEnabled = false;
  cfg.mqttUseTLS = true;
  cfg.mqttUpdateIntervalMs = 3000;
  strcpy(cfg.mqttTopicPrefix, "device");
  cfg.layoutVertical = false;
  return cfg;
}

// --- Persistent Config Helpers ---
inline void loadConfig(SystemConfig& cfg) {
  Preferences prefs;
  prefs.begin("bambu-ams", true);
  cfg = getDefaultConfig();
  if (prefs.isKey("wifiSSID"))
    prefs.getString("wifiSSID", cfg.wifiSSID, sizeof(cfg.wifiSSID));
  if (prefs.isKey("wifiPwd"))
    prefs.getString("wifiPwd", cfg.wifiPassword, sizeof(cfg.wifiPassword));
  if (prefs.isKey("printerIP"))
    prefs.getString("printerIP", cfg.printerIP, sizeof(cfg.printerIP));
  cfg.printerPort = prefs.getUShort("printerPort", cfg.printerPort);
  if (prefs.isKey("accCode"))
    prefs.getString("accCode", cfg.printerAccessCode, sizeof(cfg.printerAccessCode));
  if (prefs.isKey("printerSN"))
    prefs.getString("printerSN", cfg.printerSerial, sizeof(cfg.printerSerial));
  if (prefs.isKey("devName"))
    prefs.getString("devName", cfg.deviceName, sizeof(cfg.deviceName));
  cfg.mqttEnabled = prefs.getBool("mqttEn", cfg.mqttEnabled);
  cfg.mqttUseTLS = prefs.getBool("mqttTLS", cfg.mqttUseTLS);
  cfg.mqttUpdateIntervalMs = prefs.getULong("mqttInt", cfg.mqttUpdateIntervalMs);
  cfg.amsUnit = prefs.getUChar("amsUnit", cfg.amsUnit);
  cfg.layoutVertical = prefs.getBool("layoutVertical", false);
  prefs.end();
}

inline void saveConfig(const SystemConfig& cfg) {
  Preferences prefs;
  prefs.begin("bambu-ams", false);
  prefs.putString("wifiSSID", cfg.wifiSSID);
  prefs.putString("wifiPwd", cfg.wifiPassword);
  prefs.putString("printerIP", cfg.printerIP);
  prefs.putUShort("printerPort", cfg.printerPort);
  prefs.putString("accCode", cfg.printerAccessCode);
  prefs.putString("printerSN", cfg.printerSerial);
  prefs.putString("devName", cfg.deviceName);
  prefs.putBool("mqttEn", cfg.mqttEnabled);
  prefs.putBool("mqttTLS", cfg.mqttUseTLS);
  prefs.putULong("mqttInt", cfg.mqttUpdateIntervalMs);
  prefs.putUChar("amsUnit", cfg.amsUnit);
  prefs.putBool("layoutVertical", cfg.layoutVertical);
  prefs.end();
}

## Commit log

2026-09-23 Optimize web server and polling rates
    The ESP32 was getting heavily bogged down with the amount of polling we're doing. This optimizes the load on the ESP32, including reducing the status payload size, reducing polling rates, and adding 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
2026-09-23 Prevent failed MQTT connections from locking up the ESP32
    [bambu_printer.cpp]
2026-09-23 Add compatibility for the ESP32-S3-DevKitC board
2026-09-23 Update compiling instructions
    - Remove outdated references to Arduino IDE
    - Mention web flashing interface
    - Update building from source instructions
2026-09-23 Add 3D-printed case to BOM; cleanup related folder
    [BambuTagger-AMS2Pro.3mf]
2026-09-23 Build both boards in GitHub Actions release workflow
2026-09-23 Upgrade to latest ArduinoJson version
2026-09-23 Finish cleaning up files
    [BambuTagger-AMS.3mf, BambuTagger-AMS2Pro.3mf]
2026-09-23 Revert SPIFFS; generate embedded files
    [web_server.cpp]
2026-09-23 Change all pins for ESP32-S3-DevKitC-1
2026-09-23 Tighten status fetch interval
2026-09-23 Ensure slot numbers in debugging log start with 1
    This matches what's on the TFT display, as well as the AMS itself
2026-09-23 Mention the 100µF capacitor
2026-09-23 Read from each antenna individually to prevent cross-talk conflicts
    [rfid_manager.cpp]
2026-09-23 added PCB design files (#1)
    Fabrication files can be found in the FAB folder inside the project
    [ProPrj_BambuTagger-AMS_2026-09-22(1)-Bottom Layer.gbr, ProPrj_BambuTagger-AMS_2026-09-22(1)-Bottom Paste Mask Layer.gbr, ProPrj_BambuTagger-AMS_2026-09-22(1)-B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]
2026-09-23 Rename PCB files
    [ProPrj_BambuTagger-AMS_2026-09-22(1)-Bottom Layer.gbr, ProPrj_BambuTagger-AMS_2026-09-22(1)-Bottom Paste Mask Layer.gbr, ProPrj_BambuTagger-AMS_2026-09-22(1)-B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]
2026-09-23 Separate files/components lists for ESP-WROOM-32 and ESP32-S3-DevKitC-1
    [BambuTagger-AMS.3mf, BambuTagger-AMS2Pro.3mf]
2026-09-23 Fix bootloader offset for ESP32-S3 boards
2026-09-23 Don't show temp/humidity if sensor is not present
2026-09-30 Specify BME280 must be 3.3V variant
